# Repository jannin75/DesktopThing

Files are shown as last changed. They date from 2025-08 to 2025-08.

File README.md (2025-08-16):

# DesktopThing
Version 1.0
Please be nice this is my first time uploading a project.

This project was built using Arduino IDE, some TFT screens, an RTC module, a raspberry pi pico, FreeCAD, and a 3d printer.

This was born out of frustration about the end of remote work and heading back into the office after almost 10 years.
I wanted to make a cute little display to show a slideshow and a nice looking clock to go with it.
A desktop thing to sit on my desk and display some images and the time.

Built using a 2.8 inch ILI9341 display with an i2c capacitive touch screen and a GC9A01 round 1.28" tft display for the clock.
Uses the built in micro sd card reader on the ILI9341 and an external RTC clock with a battery to keep the time.

The .h pixel map files are used by the TFT_eSPI library to create the analog clock movement.  usersetup.h is used with the TFT_eSPI library to configure the clock display.

ClockFace7.h is an example of what your clock face files should look like.  Use one or use a bunch.  Update the .ino file to match.  I used lcd image converter to make the .h clock faces by finding printable clock faces without hands and sizing them to 240x240 to fit the screen.  Then used the converter to create the pixel map.

I used a powershell script to convert my .jpg files to 320x240 bmp files for the slide show.

The adafruit libraries are used to create the slide show and drive the tft displays.

You can set the delay for the slide show to advance near the top of the .ino file.  I also included the ability to just touch the screen to advance to the next picture if desired.

I crerated a housing in FreeCAD to hold my custom setup.  I used a prototype board and soldered the pico and some FPC connectors to the board along with the RTC.  3mf cad files are uploaded.

Full list of hardware I used:

2.8 inch 240x320 IPS Capacitive Touch Screen SPI Serial ILI9341V Driver LCD Display Module for Arduino
https://www.amazon.com/dp/B0CMGF4Q68?ref_=ppx_hzsearch_conn_dt_b_fed_asin_title_1&th=1

1.28 inch TFT LCD Display Module Round RGB 240 * 240 GC9A01 Driver 4 Wire SPI
https://www.amazon.com/dp/B0BL76Q6WS?ref_=ppx_hzsearch_conn_dt_b_fed_asin_title_1

Raspberry Pi Pico2 (also works with earlier pico) I did solder pins to it as it made it easier to prototype and solder tot he PCB.
https://www.amazon.com/dp/B0DCLF3QYB?ref_=ppx_hzsearch_conn_dt_b_fed_asin_title_2&th=1

SanDisk Ultra SDSQUNS-016G-GN3MN 16GB 80MB/s UHS-I Class 10 microSDHC Card
https://www.amazon.com/dp/B074B4P7KD?ref=ppx_yo2ov_dt_b_fed_asin_title

DS3231 Real Time Clock Module RTC
https://www.amazon.com/dp/B09SHRWHQ3?ref_=ppx_hzsearch_conn_dt_b_fed_asin_title_1&th=1

Monk Makes prototype PCD board.
https://monkmakes.com/pico_proto

FFC FPC Connector Board 8 Pins 0.5mm Socket to 2.54mm Double Row Male Pin Header Strip Adapter
https://www.amazon.com/dp/B0D79F5MWJ?ref_=ppx_hzsearch_conn_dt_b_fed_asin_title_2&th=1

FPC FFC PCB Converter Board 14P 0.5mm on Socket Side, Back 1.0mm, to DIP 2.54mm
https://www.amazon.com/dp/B0CLH5FWKN?ref=ppx_yo2ov_dt_b_fed_asin_title

Micro USB 2.0 5Pin Male to Female M to F Extension Connector
https://www.amazon.com/dp/B0CSJW27KX?ref_=ppx_hzsearch_conn_dt_b_fed_asin_title_1&th=1

I also used brass heat set insets and various screws including m2 and m3.

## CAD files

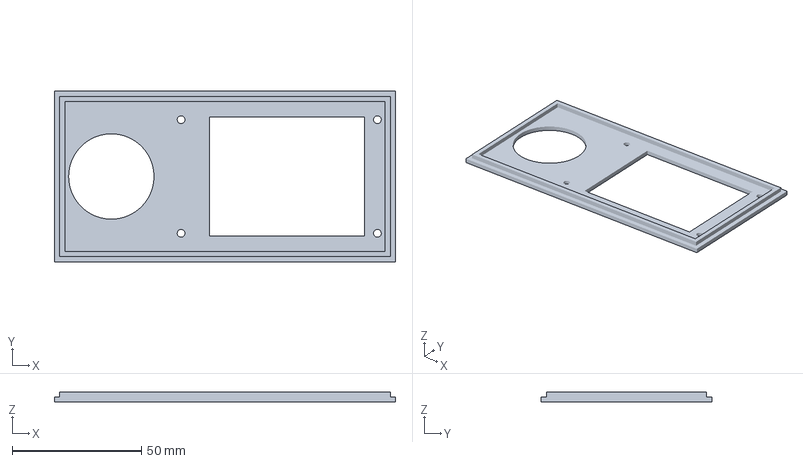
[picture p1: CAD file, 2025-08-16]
Top lid - new display with round display-BodySketch002.3mf
132.0 x 66.0 x 4.00 mm

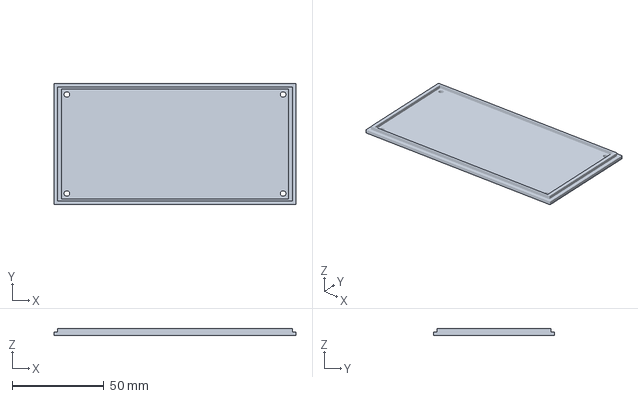
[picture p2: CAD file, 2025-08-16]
New bottom lid soldered-Body.3mf
132.0 x 66.0 x 4.00 mm

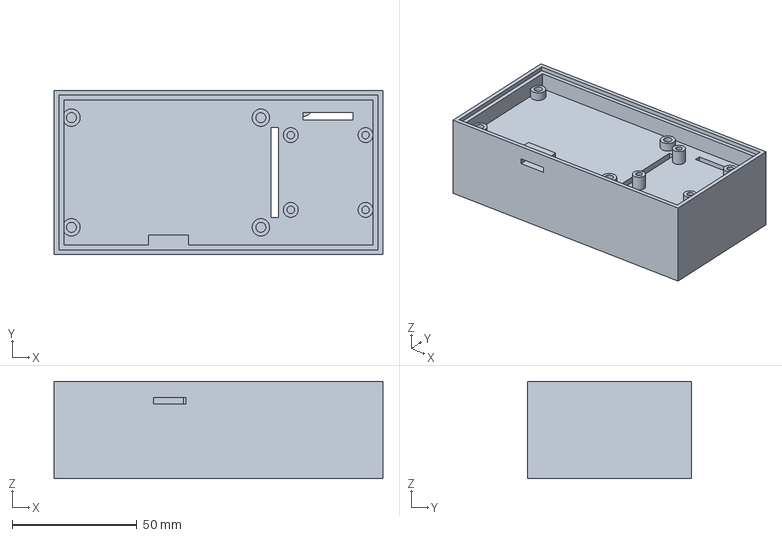
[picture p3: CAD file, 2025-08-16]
New Body Soldered PCB with pico pins-New Body SolderedSketch.3mf
132.0 x 66.0 x 39.0 mm

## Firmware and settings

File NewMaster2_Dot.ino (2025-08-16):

/***************************************************
Jeff Annin - jeff.annin@gmail.com
Parts of this shamelessly borrowed from other various examples and projects found online.

Used to create a desktop thing that has a clock and displays pictures.
My own version of a custom made digital picture frame with a customized
cloock face.  Future plans might include replacing the clock with a wireless
phone charger and using a larger screen for the slideshow.  I might also
get the touchscreen part working and use it to set the time/date and
possibly brightness and other options.

This uses TFT-eSPI and Adafruit_GFX which might be inefficient and redundant but it worked.
I did this mainly because TFT_eSPI did a good job with the clock using bitmaps and sprites, but
didn't support multiple screens with different drivers.  I also had a workign slideshow project
that used Adafruit_GFX so I just combined them.  It would have been nice to use just one of them.

Built using a Raspberry pi pico because I had them laying around when I got started
working with microcontrollers.  Uses setup/setup1 and loop/loop1 to use both processors
to run each part of the project(clock/slideshow) separately.

I built this project using a breakout/dev board for the pico and 3d printed a housing to hold it.
I did this because I have commitment issues and like the idea that I could just pop the pico out and
use it for somethign else or replace it with a Pico 2 or Pico W in the future without needing
to resolder or change too much.  It also allows me to do the same with the other components.

Hardware used:
ILI9341 2.8 inch tft SPI display with built in micro sd card reader and i2c cap touch
GC9A01A 1.28 inch round tft SPI display
DS3231 RTC clock
Raspberry Pi Pico RP2040 standard setup
A breakout/dev board for the pico that has a socket for the pico and power and GPIO pins
An external 9v power supply for the breakout/dev board.
Bambu A1 mini 3d printer and various brass heat inserts, screws, and standoffs.

Full details can be found here: http://someurl.com
****************************************************/

//Core libraries
#include <SPI.h>                  //Core SPI library
#include <Adafruit_GFX.h>         //Adafruit GFX graphics library
#include <Adafruit_ILI9341.h>     //ILI9341 adafruit Hardware-specific library for slideshow
#include <SD.h>                   //SD card/filesystem library
#include <TFT_eSPI.h>             //TFT_eSPI graphics library for clock sprites
#include <RTClib.h>               //RTC Library
#include <Wire.h>                 //i2c support for RTC/touch module
#include <Adafruit_FT6206.h>      //Adafruit Cap Touch Library

// ili9341 pins for adafruit gfx
#define TFT1_CS 17	//PICO SPI0 CSn
#define TFT1_MISO 16	//PICO SPI0 RX
#define TFT1_MOSI 19	//PICO SPI0 TX
#define TFT1_CLK 18	//PICO SPI0 SCK
#define TFT1_RST 21	//PICO GP1
#define TFT1_DC 20	//PICO GP0
#define SD_CS 22   //GPIO 22

//cap touch pins - using same i2c as rtc
#define CTP_INT 2
#define CTP_SDA 0
#define CTP_RST //to 3.3v
#define CTP_SCL 1

//ili9341 display setup using adafruit gfx
Adafruit_ILI9341 tft = Adafruit_ILI9341(TFT1_CS, TFT1_DC, TFT1_RST);

//GC9A01A display setup - pins can be found in user_setup.h under the TFT_eSPI library used for the clock
TFT_eSPI tft2 = TFT_eSPI();

//RTC setup
RTC_DS3231 rtc;

//Cap touch on ili9341 setup
Adafruit_FT6206 touch = Adafruit_FT6206();

//Slideshow stuff
char *Files[1000];
int Filecounter = 0;
int slideshowinterval = 60000;   //ms between images in slideshow
#define BUFFPIXEL 20

// These read 16- and 32-bit types from the SD card file.
// BMP data is stored little-endian, Arduino is little-endian too.
// May need to reverse subscript order if porting elsewhere.
uint16_t read16(File f) {
  uint16_t result;
  ((uint8_t *)&result)[0] = f.read(); // LSB
  ((uint8_t *)&result)[1] = f.read(); // MSB
  return result;
}

uint32_t read32(File f) {
  uint32_t result;
  ((uint8_t *)&result)[0] = f.read(); // LSB
  ((uint8_t *)&result)[1] = f.read();
  ((uint8_t *)&result)[2] = f.read();
  ((uint8_t *)&result)[3] = f.read(); // MSB
  return result;
}

//Loading .h bitmaps for clock face and hands
#include "ClockFace1.h"   // File with ClockFace1.h pixel map - BT image
#include "ClockFace2.h"   // File with ClockFace2.h pixel map - Huskers simple red N
#include "ClockFace3.h"   // File with ClockFace3.h pixel map - Huskers Black with red N white numbers
#include "ClockFace4.h"   // File with ClockFace4.h pixel map - Light blue with roman numerals
#include "ClockFace5.h"   // File with ClockFace5.h pixel map - Blue big numbers
#include "ClockFace6.h"   // File with ClockFace5.h pixel map - Huskers Blackshirts
#include "ClockFace7.h"   // File with ClockFace5.h pixel map - Neon 
#include "hourHand.h"     // File with hour hand pixel map - Black
#include "minuteHand.h"   // File with minute hand pixel map - Black
#include "secondHand.h"   // File with seconds hand pixel map
#include "minuteHandW.h"  // File with minutes hand pixel map - White
#include "hourHandW.h"    // File with hour hand pixel map - White

//clock related definitions
int centerX = tft2.width() / 2;  // Adjust for your display size
int centerY = tft2.height() / 2;  // Adjust for your display size
int radius = tft2.width() / 2; // Adjust for your display size
int sDeg,mDeg,hDeg;
unsigned long ms = millis();
unsigned long mms = millis();
byte start = 1;         // initial start flag
byte display_sHand = 1; // display seconds hand 0=no, 1=yes
volatile int hh = 0;    // hours variable
volatile int mm = 0;    // minutes variable
volatile int ss = 0;    // seconds variable
volatile int MM = 00;    // month variable
volatile int DD = 00;    // day variable
volatile int YYYY = 0000;  // year variable
int ClockFaceChoice = 1;
bool initial = 1;
char buffer[20];
char d[32];
char t[32];

#define SIXTIETH 0.016666667
#define TWELFTH 0.08333333
#define SIXTIETH_RADIAN 0.10471976
#define TWELFTH_RADIAN 0.52359878
#define RIGHT_ANGLE_RADIAN 1.5707963
#define DEG2RAD 0.0174532925

//colors
#define buttonColor ILI9341_BLUE
#define MARK_COLOR 0x0000    //Clock Marks
#define SUBMARK_COLOR 0xF800 //Clock Marks

int mcounter = 0;

TFT_eSprite clock_Face = TFT_eSprite(&tft2);   // Declare Sprite object "spr" with pointer to "tft" object
TFT_eSprite second_Hand = TFT_eSprite(&tft2);  // Declare Sprite object "spr" with pointer to "tft" object
TFT_eSprite minute_Hand = TFT_eSprite(&tft2);  // Declare Sprite object "spr" with pointer to "tft" object
TFT_eSprite hour_Hand = TFT_eSprite(&tft2);    // Declare Sprite object "spr" with pointer to "tft" object

// global x y for cap touch
int BtnX, BtnY;

// other menu related items
volatile bool setupStatus = true;
volatile bool setupMenu = false;
volatile bool setupFace = false;
volatile bool DateOn = true;
int scounter = 0;
bool inRange(int val, int minimum, int maximum) {
  return ((minimum <= val) && (val <= maximum));
}

void setup() {
  //Slideshow/Touch related setup
  //Start serial interface
  Serial.begin(115200);
  delay(500);
  Serial.println("Section setup() - Section Begin");

  //init RTC
  Wire.setSDA (CTP_SDA);
  Wire.setSCL (CTP_SCL);
  if (! rtc.begin()) {
    Serial.println("Section setup() - RTC not found");
    Serial.flush();
    while (1) delay(10);
  }
  Serial.println("Section setup() - RTC init succeeded!");
  
  //init ili9341 adafruit gfx display
  tft.begin();           //Initialize screen
  tft.invertDisplay(1);  //invert colors for ili9341
  tft.setRotation(1);    //set ili9341 landscape
  tft.fillScreen(ILI9341_BLACK);    //fill screen with black
  tft.setTextColor(ILI9341_WHITE);  //set text color to white
  tft.setCursor( 10, 20 );          //set place to start printing text
  tft.print("ILI9341 tft screen init succeeded.");   //print status message on ili9341 display
  Serial.println(F("Section setup() - ILI9341 tft screen init succeeded."));  //print status to serial
  delay(1000);    //wait 1 second to display status

    //init sd card
  Serial.println(F("Section setup() - Initializing filesystem..."));
  if(!SD.begin(SD_CS, SD_SCK_MHZ(20))) {
    Serial.println(F("Section setup() - SD begin() failed"));
    tft.setCursor( 10, 30 );
    tft.print("SD card init failed");   //display test message to ili9341 display
    delay(1000);  //wait one minute to display error
    for(;;); // Fatal error, do not continue
  }
  File root = SD.open("/");  // open SD card main root
  //delay(100);
  //printDirectory(root, 0);   //print directory to serial
  tft.setCursor(10, 30);
  tft.print("SD card init succeeded");   //display test message to ili9341 display
  Serial.println("Section setup() - SD init succeeded!");
  delay(1000);    //wait 1 second to display status  

  //init touch
  //Wire.setSDA (CTP_SDA);
  //Wire.setSCL (CTP_SCL);
  if (! touch.begin(50, &Wire)) {  // pass in 'sensitivity' coefficient and I2C bus
   Serial.println("Section setup() - FT6X36 init failed");  //debug info
   while (1) delay(10);
  }
  tft.setCursor(10, 40);
  tft.print("Touch Screen init succeeded");   
  Serial.println("Section setup() - FT6X36 Touch Screen init succeeded.");  //debug info
  delay(1000);    //wait 1 second to display status 

  //draw choice buttons
  drawChoice();
  static long onesecond = 1000;
  static long pMillis = 0;
  unsigned long countdownValue, prevMillis, currentMillis;
  unsigned long startMillis = millis();
  //how long to wait before continue?
  countdownValue = 10;
  //wait for button press
  while (setupStatus) {
    if(millis() - startMillis > onesecond) {
      //Serial.println("Section loop() - is this showing every second?");  //debug info
      startMillis = millis();  //reset startMillis value
      tft.fillRect(85, 200, 20, 30, ILI9341_BLACK);
      tft.setCursor(85,200);
      tft.print(countdownValue);
      countdownValue --;
      if (countdownValue == 0) {
        setupStatus = 0;
      }
    }
    if (touch.touched()) {
      ProcessTouch(); // get screen location actuall x-y
      if ((inRange(BtnX, 100, 130)) && (inRange(BtnY,20,140))) {  // was the setup button pressed?
        Serial.println("Section loop() - Set time button pressed!");
        //enter setup function
        setupMenu = 1;
        setupStatus = 0;
        drawSetup();
       // drawSetup();
      } else if ((inRange(BtnX, 30, 90)) && (inRange(BtnY,70,220))) {  // was the continue button pressed?
        Serial.println("Section loop() - Continue button pressed!");
        //Continue
        setupMenu = 0;
        setupStatus = 0;
      } else if ((inRange(BtnX, 100, 130)) && (inRange(BtnY,170,290))) {  // was the continue button pressed?
        Serial.println("Section loop() - Set Face button pressed!");
        //draw buttons
        drawFaceButtons();
        setupFace = 1;
        setupMenu = 0;
        setupStatus = 0;
      } 
    }
  }
  while (setupFace) {
    //process touches
    if (touch.touched()) {
      ProcessTouch(); // get screen location actuall x-y
      if ((inRange(BtnX, 20, 55)) && (inRange(BtnY, 15, 135))) {  // was the exit setup button pressed?
        Serial.println("Section loop() - Exit Setup Pressed");
        setupFace = 0;        
      } else if ((inRange(BtnX, 180, 200)) && (inRange(BtnY, 20, 120))) {  // Face 1
        Serial.println("Section loop() - Face 1 pressed");
        ClockFaceChoice = 1;
      } else if ((inRange(BtnX, 140, 170)) && (inRange(BtnY, 20, 120))) {  // Face 2
        Serial.println("Section loop() - Face 2 pressed");
        ClockFaceChoice = 2;
      } else if ((inRange(BtnX, 110, 130)) && (inRange(BtnY, 20, 120))) {  // Face 3
        Serial.println("Section loop() - Face 3 pressed");
        ClockFaceChoice = 3;
      } else if ((inRange(BtnX, 60, 90)) && (inRange(BtnY, 20, 120))) {  // Face 4
        Serial.println("Section loop() - Face 4 pressed");
        ClockFaceChoice = 4;
      } else if ((inRange(BtnX, 180, 200)) && (inRange(BtnY, 200, 240))) {  // Face 5
        Serial.println("Section loop() - Face 5 pressed");
        ClockFaceChoice = 5;
      } else if ((inRange(BtnX, 140, 170)) && (inRange(BtnY, 200, 240))) {  // Face 6
        Serial.println("Section loop() - Face 6 pressed");
        ClockFaceChoice = 6;
      } else if ((inRange(BtnX, 110, 130)) && (inRange(BtnY, 200, 240))) {  // Face 7
        Serial.println("Section loop() - Face 7 pressed");
        ClockFaceChoice = 7;
      } else if ((inRange(BtnX, 30, 60)) && (inRange(BtnY, 180, 290))) {  // was the Date ON/Off button pressed?
        Serial.println("Section loop() - Date On/Off Setup Pressed");
        if (DateOn == 1) {
          DateOn = 0;
        } else {
          DateOn = 1;
        }
      }
    }
  }

  while (setupMenu && !setupFace) {
    if(millis() - pMillis > onesecond) {
      //Serial.println("Section loop() - is this showing every second?");  /debug info
      pMillis = millis();
      //get time and load then display
      DateTime now = rtc.now();  //get current time
      tft.fillRect(15, 175, 100, 20, ILI9341_BLACK);
      tft.setCursor(15, 175);
      sprintf(t, "%02d:%02d:%d \n", now.hour(), now.minute(), now.second());  //load formatted time into "t"
      tft.print(t);
      
      tft.setCursor(165, 160);
      tft.print("Current date:");
      tft.fillRect(165, 175, 140, 20, ILI9341_BLACK);
      tft.setCursor(165, 175);
      sprintf(d, "%02d/%02d/%d \n", now.month(), now.day(), now.year());  //load formatted date info into "d"
      tft.print(d);
    }
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
void loop() {
  //Setup Menu
  //Populate time from RTC to clock variables
  Serial.println("Section loop() - Section start");  //debug info

  //Slideshow loop
  Serial.println("Section loop() - Start slideshow");
  File root = SD.open("/");  // open SD card main root
  
  //Display a loop of bmp files from the root fo the SD card
  while (true) {
    tft.fillScreen(ILI9341_BLACK);
    File entry =  root.openNextFile();

    if (! entry) {
      // no more files - begin loop again
      root.close();
      return;
    }
    String filename = String(entry.name());  // get file name
    Serial.println("Next File is:");
    Serial.println(filename);
    uint8_t nameSize = String(entry.name()).length();  // get file name size
    String str1 = String(entry.name()).substring( nameSize - 4 );  // save the last 4 characters (file extension)

    if (str1.equalsIgnoreCase(".bmp")) {  // if the file has '.bmp' extension
      bmpDraw(entry.name(), 0, 0);  //  draw BMP
      entry.close();  // close the file
      unsigned long showTime = millis();
      bool advance = false;
    //Do we advance to the next image? Touch or interval?
      while (!advance) {
        if (touch.touched()) {
          ProcessTouch();
          advance = true;
        }
        if (millis() - showTime >= slideshowinterval) {
        advance = true;
        }
      //delay(slideshowinterval);   // delay and then go on to the next bmp file in loop
      delay(50);
      }

    } else {
      Serial.println("Not .bmp file, skipping");    //if not a bmp file close and move on
      entry.close();
    }
  }
  Serial.println("Section loop() - Section end");
}

void loop1() {
  manage_Display();           // manage clock display
}

void manage_Display() {
// Only update the screen once every second and at the start
  if(millis()-ms>=1000 || start) {
    
    //add to counter until 60 and update the date
    mcounter++;
    if (mcounter==60) {
      Serial.println("A minute has passed! Updating Date");
      DateTime now = rtc.now();
      sprintf(d, "%02d/%02d/%d \n", now.month(), now.day(), now.year());
      Serial.println(d);
      hh = now.hour();
      mm = now.minute();
      ss = now.second();
      mcounter =0;
    }

    //main clock workings
    ms = millis();
    if(++ss>59) {
      ss=0;
      if(++mm>59) {
        mm=0;
        if(++hh>23) hh=0;
      }
    }
    
    // Set the angles for the Second, Minute and Hour hands
    sDeg = ss*6;
    if(ss==0 || start) {
      start = 0;
      if(ss==0) mms = millis();
      mDeg = mm*6+sDeg/60;
      hDeg = hh*30+mDeg/12;
      }
    clockUpdate(sDeg,mDeg,hDeg); // call routine to push the sprites for the clock face and clock hands
  }
}

// Create Seconds hand sprite and push the image of the Seconds hand to that sprite
void createSecondHand() {
  second_Hand.setColorDepth(8); // set for 8 bits per pixel
  second_Hand.createSprite(10,136);
  second_Hand.pushImage(0,0,10,136,secondHand);
  second_Hand.setPivot(5,102);
}

// Create Minutes hand sprite and push the image of the Minutes hand to that sprite
void createMinuteHand() {
  minute_Hand.setColorDepth(8);
  minute_Hand.createSprite(7,100);
  minute_Hand.pushImage(0,0,7,100,minuteHandW);
  minute_Hand.setPivot(4,79);
}

// Create Hour hand sprite and push the image of the Hour hand to that sprite
void createHourHand() {
  hour_Hand.setColorDepth(8);
  hour_Hand.createSprite(9,74);
  hour_Hand.pushImage(0,0,9,74,hourHandW);
  hour_Hand.setPivot(5,51);
}

// Create the background sprite i.e. the clock face and push the image of the clock face to that sprite and display date
void createBackground() {
  clock_Face.setColorDepth(16);
  clock_Face.createSprite(240,240);
  clock_Face.setPivot(120,120);
  tft2.setPivot(120,120);
  clock_Face.setTextColor(TFT_WHITE);
  clock_Face.fillSprite(TFT_TRANSPARENT);
  //select correct clock face
  if (ClockFaceChoice == 1) {
    clock_Face.pushImage(0,0,240,240,ClockFace1);
  } else if (ClockFaceChoice == 2) {
    clock_Face.pushImage(0,0,240,240,ClockFace2);
  } else if (ClockFaceChoice == 3) {
    clock_Face.pushImage(0,0,240,240,ClockFace3);
  } else if (ClockFaceChoice == 4) {
    clock_Face.pushImage(0,0,240,240,ClockFace4);
  } else if (ClockFaceChoice == 5) {
    clock_Face.pushImage(0,0,240,240,ClockFace5);
  } else if (ClockFaceChoice == 6) {
    clock_Face.pushImage(0,0,240,240,ClockFace6);
  } else if (ClockFaceChoice == 7) {
    clock_Face.pushImage(0,0,240,240,ClockFace7);
  }
  if (DateOn == 1) {
    clock_Face.setTextSize(1);
    clock_Face.setTextColor(TFT_WHITE);
    clock_Face.fillRect(78, 200, 80, 16, ILI9341_BLACK);
    clock_Face.drawString(d, 80, 200, 2);
  }
  //this section can be used to draw marks or numbers if needed
  //Draw 60 clock marks
  //first two numbers are the ring radius large hour marks(12.3.6.9), second two are hours,  thrid two are minutes/seconds
  //draw_round_clock_mark(104, 120, 112, 120, 114, 114);
}

// On each update, re-create the clock face, and push the sprites of the Seconds, Minutes and Hour hands to their new positions on the display
void clockUpdate(int16_t angle_secondHand, int16_t angle_minuteHand, int16_t angle_hourHand) {
  createBackground();
  if (display_sHand) second_Hand.pushRotated(&clock_Face, angle_secondHand, TFT_TRANSPARENT); // Check if Seconds hand is to be displayed
  minute_Hand.pushRotated(&clock_Face, angle_minuteHand, TFT_TRANSPARENT);
  hour_Hand.pushRotated(&clock_Face, angle_hourHand, TFT_TRANSPARENT);
  clock_Face.pushSprite(0,0,TFT_TRANSPARENT);
}

void bmpDraw(const char *filename, uint8_t x, uint16_t y) {
  // function to draw the bmp files - could add this to another library to save space here?
  File     bmpFile;
  int      bmpWidth, bmpHeight;   // W+H in pixels
  uint8_t  bmpDepth;              // Bit depth (currently must be 24)
  uint32_t bmpImageoffset;        // Start of image data in file
  uint32_t rowSize;               // Not always = bmpWidth; may have padding
  uint8_t  sdbuffer[3 * BUFFPIXEL]; // pixel buffer (R+G+B per pixel)
  uint8_t  buffidx = sizeof(sdbuffer); // Current position in sdbuffer
  boolean  goodBmp = false;       // Set to true on valid header parse
  boolean  flip    = true;        // BMP is stored bottom-to-top
  int      w, h, row, col;
  uint8_t  r, g, b;
  uint32_t pos = 0, startTime = millis();

  //check image size is within the screen size
  if ((x >= tft.width()) || (y >= tft.height())) return;

  //print status to serial interface
  Serial.println();
  Serial.print(F("Loading image '"));
  Serial.print(filename);
  Serial.println('\'');

  // Open requested file on SD card
  if ((bmpFile = SD.open(filename)) == NULL) {
    Serial.print(F("File not found"));
    return;
  }

  // Parse BMP header
  if (read16(bmpFile) == 0x4D42) { // BMP signature
    Serial.print(F("File size: ")); Serial.println(read32(bmpFile));
    (void)read32(bmpFile); // Read & ignore creator bytes
    bmpImageoffset = read32(bmpFile); // Start of image data
    Serial.print(F("Image Offset: ")); Serial.println(bmpImageoffset, DEC);
    // Read DIB header
    Serial.print(F("Header size: ")); Serial.println(read32(bmpFile));
    bmpWidth  = read32(bmpFile);
    bmpHeight = read32(bmpFile);
    if (read16(bmpFile) == 1) { // # planes -- must be '1'
      bmpDepth = read16(bmpFile); // bits per pixel
      Serial.print(F("Bit Depth: ")); Serial.println(bmpDepth);
      if ((bmpDepth == 24) && (read32(bmpFile) == 0)) { // 0 = uncompressed

        goodBmp = true; // Supported BMP format -- proceed!
        Serial.print(F("Image size: "));
        Serial.print(bmpWidth);
        Serial.print('x');
        Serial.println(bmpHeight);

        // BMP rows are padded (if needed) to 4-byte boundary
        rowSize = (bmpWidth * 3 + 3) & ~3;

        // If bmpHeight is negative, image is in top-down order.
        // This is not canon but has been observed in the wild.
        if (bmpHeight < 0) {
          bmpHeight = -bmpHeight;
          flip      = false;
        }

        // Crop area to be loaded
        w = bmpWidth;
        h = bmpHeight;
        if ((x + w - 1) >= tft.width())  w = tft.width()  - x;
        if ((y + h - 1) >= tft.height()) h = tft.height() - y;

        // Set TFT address window to clipped image bounds
        tft.startWrite();
        tft.setAddrWindow(x, y, w, h);

        for (row = 0; row < h; row++) { // For each scanline...
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

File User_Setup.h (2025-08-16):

																	//                            USER DEFINED SETTINGS
//   Set driver type, fonts to be loaded, pins used and SPI control method etc.
//
//   See the User_Setup_Select.h file if you wish to be able to define multiple
//   setups and then easily select which setup file is used by the compiler.
//
//   If this file is edited correctly then all the library example sketches should
//   run without the need to make any more changes for a particular hardware setup!
//   Note that some sketches are designed for a particular TFT pixel width/height

// User defined information reported by "Read_User_Setup" test & diagnostics example
#define USER_SETUP_INFO "User_Setup"

// Define to disable all #warnings in library (can be put in User_Setup_Select.h)
//#define DISABLE_ALL_LIBRARY_WARNINGS

// ##################################################################################
//
// Section 1. Call up the right driver file and any options for it
//
// ##################################################################################

// Define STM32 to invoke optimised processor support (only for STM32)
//#define STM32

// Defining the STM32 board allows the library to optimise the performance
// for UNO compatible "MCUfriend" style shields
//#define NUCLEO_64_TFT
//#define NUCLEO_144_TFT

// STM32 8-bit parallel only:
// If STN32 Port A or B pins 0-7 are used for 8-bit parallel data bus bits 0-7
// then this will improve rendering performance by a factor of ~8x
//#define STM_PORTA_DATA_BUS
//#define STM_PORTB_DATA_BUS

// Tell the library to use parallel mode (otherwise SPI is assumed)
//#define TFT_PARALLEL_8_BIT
//#defined TFT_PARALLEL_16_BIT // **** 16-bit parallel ONLY for RP2040 processor ****

// Display type -  only define if RPi display
//#define RPI_DISPLAY_TYPE // 20MHz maximum SPI

// Only define one driver, the other ones must be commented out
//define ILI9341_DRIVER       // Generic driver for common displays
//#define ILI9341_2_DRIVER     // Alternative ILI9341 driver, see https://github.com/Bodmer/TFT_eSPI/issues/1172
//#define ST7735_DRIVER      // Define additional parameters below for this display
//#define ILI9163_DRIVER     // Define additional parameters below for this display
//#define S6D02A1_DRIVER
//#define RPI_ILI9486_DRIVER // 20MHz maximum SPI
//#define HX8357D_DRIVER
//#define ILI9481_DRIVER
//#define ILI9486_DRIVER
//#define ILI9488_DRIVER     // WARNING: Do not connect ILI9488 display SDO to MISO if other devices share the SPI bus (TFT SDO does NOT tristate when CS is high)
//#define ST7789_DRIVER      // Full configuration option, define additional parameters below for this display
//#define ST7789_2_DRIVER    // Minimal configuration option, define additional parameters below for this display
//#define R61581_DRIVER
//#define RM68140_DRIVER
//#define ST7796_DRIVER
//#define SSD1351_DRIVER
//#define SSD1963_480_DRIVER
//#define SSD1963_800_DRIVER
//#define SSD1963_800ALT_DRIVER
//#define ILI9225_DRIVER
#define GC9A01_DRIVER

// Some displays support SPI reads via the MISO pin, other displays have a single
// bi-directional SDA pin and the library will try to read this via the MOSI line.
// To use the SDA line for reading data from the TFT uncomment the following line:

// #define TFT_SDA_READ      // This option is for ESP32 ONLY, tested with ST7789 and GC9A01 display only

// For ST7735, ST7789 and ILI9341 ONLY, define the colour order IF the blue and red are swapped on your display
// Try ONE option at a time to find the correct colour order for your display

//  #define TFT_RGB_ORDER TFT_RGB  // Colour order Red-Green-Blue
//  #define TFT_RGB_ORDER TFT_BGR  // Colour order Blue-Green-Red

// For M5Stack ESP32 module with integrated ILI9341 display ONLY, remove // in line below

// #define M5STACK

// For ST7789, ST7735, ILI9163 and GC9A01 ONLY, define the pixel width and height in portrait orientation
// #define TFT_WIDTH  80
// #define TFT_WIDTH  128
// #define TFT_WIDTH  172 // ST7789 172 x 320
// #define TFT_WIDTH  170 // ST7789 170 x 320
// #define TFT_WIDTH  240 // ST7789 240 x 240 and 240 x 320
// #define TFT_HEIGHT 160
// #define TFT_HEIGHT 128
// #define TFT_HEIGHT 240 // ST7789 240 x 240
// #define TFT_HEIGHT 320 // ST7789 240 x 320
// #define TFT_HEIGHT 240 // GC9A01 240 x 240

// For ST7735 ONLY, define the type of display, originally this was based on the
// colour of the tab on the screen protector film but this is not always true, so try
// out the different options below if the screen does not display graphics correctly,
// e.g. colours wrong, mirror images, or stray pixels at the edges.
// Comment out ALL BUT ONE of these options for a ST7735 display driver, save this
// this User_Setup file, then rebuild and upload the sketch to the board again:

// #define ST7735_INITB
// #define ST7735_GREENTAB
// #define ST7735_GREENTAB2
// #define ST7735_GREENTAB3
// #define ST7735_GREENTAB128    // For 128 x 128 display
// #define ST7735_GREENTAB160x80 // For 160 x 80 display (BGR, inverted, 26 offset)
// #define ST7735_ROBOTLCD       // For some RobotLCD Arduino shields (128x160, BGR, https://docs.arduino.cc/retired/getting-started-guides/TFT)
// #define ST7735_REDTAB
// #define ST7735_BLACKTAB
// #define ST7735_REDTAB160x80   // For 160 x 80 display with 24 pixel offset

// If colours are inverted (white shows as black) then uncomment one of the next
// 2 lines try both options, one of the options should correct the inversion.

#define TFT_INVERSION_ON
// #define TFT_INVERSION_OFF


// ##################################################################################
//
// Section 2. Define the pins that are used to interface with the display here
//
// ##################################################################################

//MY SETTINGS FOR PICO GP1
#define TFT_CS 13	//PICO SPI0 CSn
//#define TFT_MISO 12	//PICO SPI0 RX
#define TFT_MOSI 15	//PICO SPI0 TX SDA
#define TFT_SCLK 14	//PICO SPI0 SCK
#define TFT_RST 10	//PICO GP1
#define TFT_DC 11	//PICO GP0

// If a backlight control signal is available then define the TFT_BL pin in Section 2
// below. The backlight will be turned ON when tft.begin() is called, but the library
// needs to know if the LEDs are ON with the pin HIGH or LOW. If the LEDs are to be
// driven with a PWM signal or turned OFF/ON then this must be handled by the user
// sketch. e.g. with digitalWrite(TFT_BL, LOW);

// #define TFT_BL   32            // LED back-light control pin
// #define TFT_BACKLIGHT_ON HIGH  // Level to turn ON back-light (HIGH or LOW)
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
